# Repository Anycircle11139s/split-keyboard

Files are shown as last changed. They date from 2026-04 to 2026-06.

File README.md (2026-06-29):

# split-keyboard

Readme time...

I created a split keyboard, because I really enjoyed making the hackpad and I spend a lot of time on my computer and don't wanna get carpal tunnel. I spent a really long time making the split keyboard and it's a bit basic, but I like it. 

Screenshot 2026-04-14 at 10 44 15 am
This is the code, its pretty simple, but I didn't want to make it too complex as it is my first time working with zmk (I used kmk for the hackpad before)

Screenshot 2026-04-13 at 3 55 50 pm
This is my PCB, I spent a while placing the keys in a format that I liked, but I spet a lot longer routing the thing. I lowkenuinely spent like 7 hours just routing it :I

Screenshot 2026-04-13 at 3 56 20 pm
Screenshot 2026-04-13 at 3 56 32 pm

Here, I have the case, I'm pretty proud of it because there was no tutorial and I had to wing it, but it still turned out pretty well.Screenshot 2026-04-14 at 10 56 33 am

The schematic was pretty fun, I made hierarchial sheets and a rlly big keyboard matrix, it was overall pretty easy (the schematic)

BOM:

|Name |Purpose |Quantity|Total Cost (USD)|Link |Distributor |
|---|---|---|---|---|---|
|Soldering iron tip cleaner |To get solder off my soldering iron when soldering the split keyboard|1 |2.51 |https://www.aliexpress.com/item/1005011767599627.html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 |ali-express |
|Tweezers |So i can place small stuff on a board |1 |3.80 |https://www.aliexpress.com/item/1005008096741092.html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 |Ali-express |
|Wick |So if I make mistakes i can suck up the solder |1 |1.90 |https://www.aliexpress.com/item/1005005111965242.html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 |Ali-express |
|Helping hands |to allow me to solder all the stuff |1 |1.50 |https://www.aliexpress.com/item/1005011766151305.html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 |Ali-express |
|M3X4X5 Heat Insert Nut M3 Threaded|for inseting pcb t case |50 |2.88 |https://www.aliexpress.com/item/1005010775775055.html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 |Ali-express |
|Case printing and shipping |The case |1 |7.00 | |Printing Legion|
|PCB |The board which the components go on |1 |31.50 | |JLCPCB |
|xiao nRF52840 |microcontroller |2 |13.62 |https://www.aliexpress.com/item/1005006988954136.html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 |Ali-express |
|Diodes |to prevent ghosting |100 |0.86 |https://www.aliexpress.com/item/32947233235.html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|Ali-express |
|M2 screws |to hold it together |50 |1.90 |https://www.aliexpress.com/item/1005005070119421.html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 |Ali-express |
|Keycaps |to cover the keys |124 |3.93 |https://www.aliexpress.com/item/1005007360831985.html |Ali-express |
|Switches |Buttons for keyboard |110 |16.00 |https://www.aliexpress.com/item/1005004285423123.html |Ali-express |

<br>

<br>

Building keyboard:
<br>
So I spent a rlly long time sodlering everything together and after a couple bugs and troubleshooting, I finally got it working. I'm really proud of my design and I can't wait to show this off to all my friends and family!
<br>
<br>

WhatsApp Image 2026-06-30 at 09 35 08 (1)

https://github.com/user-attachments/assets/18d752bb-31d4-4ef4-a61a-be9153cc65bb

https://github.com/user-attachments/assets/6f350401-69de-47bb-a7fa-8a00cfc4a692

WhatsApp Image 2026-06-30 at 09 35 08

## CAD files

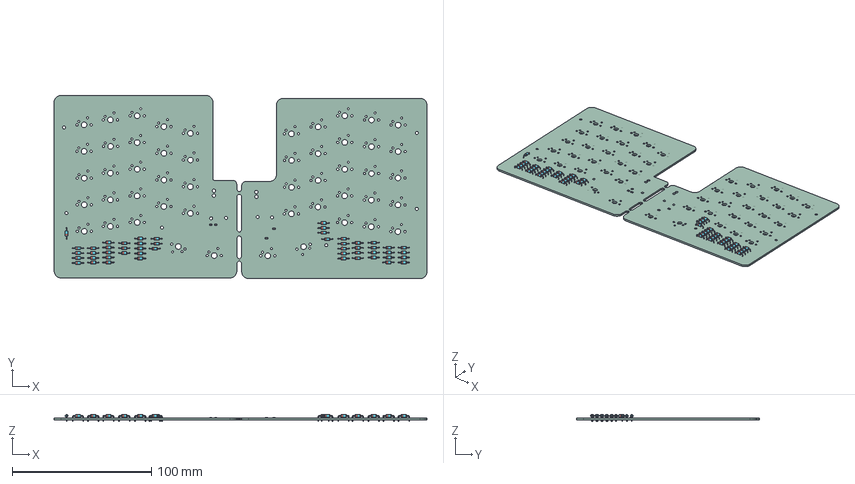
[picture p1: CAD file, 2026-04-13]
Split keyboard PCB/Split keyboard.step
267.4 x 131.4 x 5.01 mm
D_DO-35_SOD27_P7.62mm_Horizontal x 50
R_0805_2012Metric x 4
Split keyboard_PCB

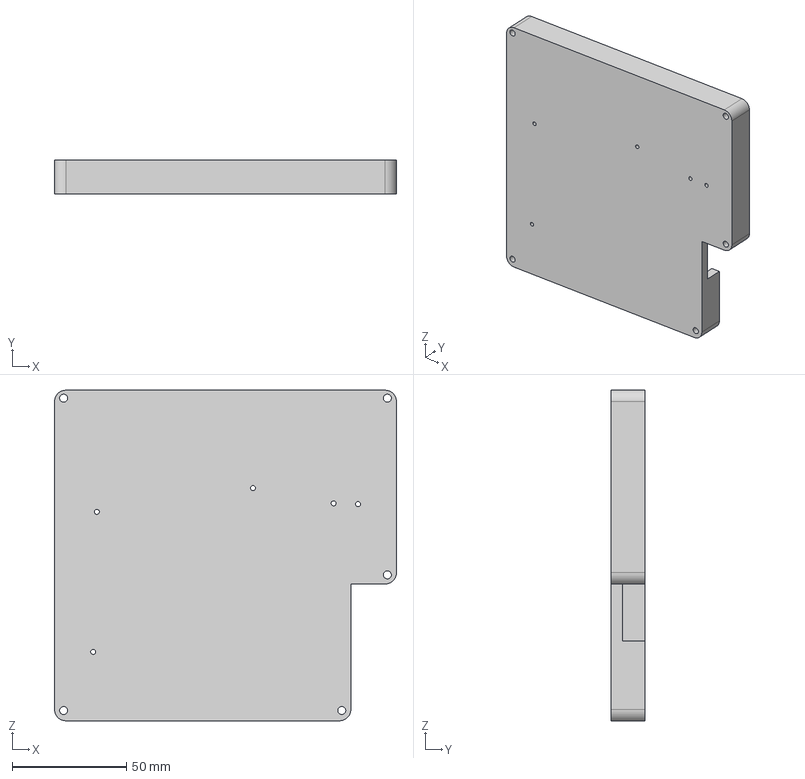
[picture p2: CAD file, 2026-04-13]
Splot keyboard Production/Left bottom split keyboard case.step
150.0 x 15.0 x 145.0 mm

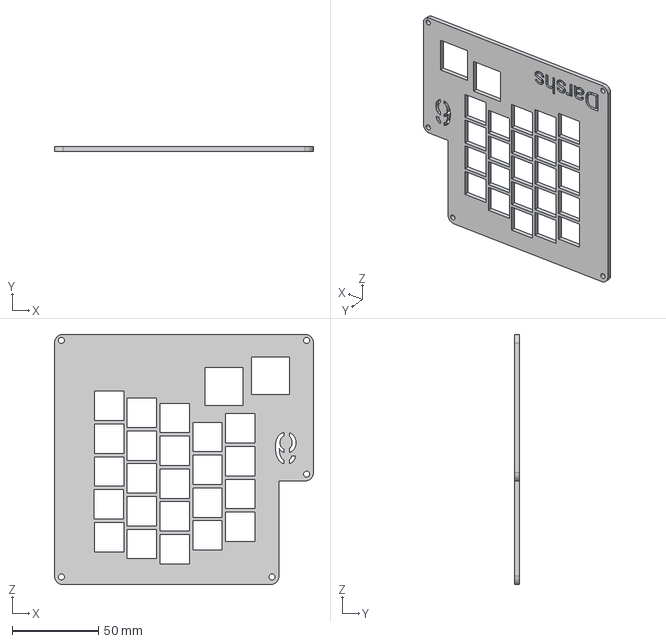
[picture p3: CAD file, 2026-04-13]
Splot keyboard Production/Left top split keyboard case.step
150.0 x 3.00 x 145.0 mm

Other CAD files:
Splot keyboard Production/Right bottom split keyboard case.step
Splot keyboard Production/Right top split keyboard case.step

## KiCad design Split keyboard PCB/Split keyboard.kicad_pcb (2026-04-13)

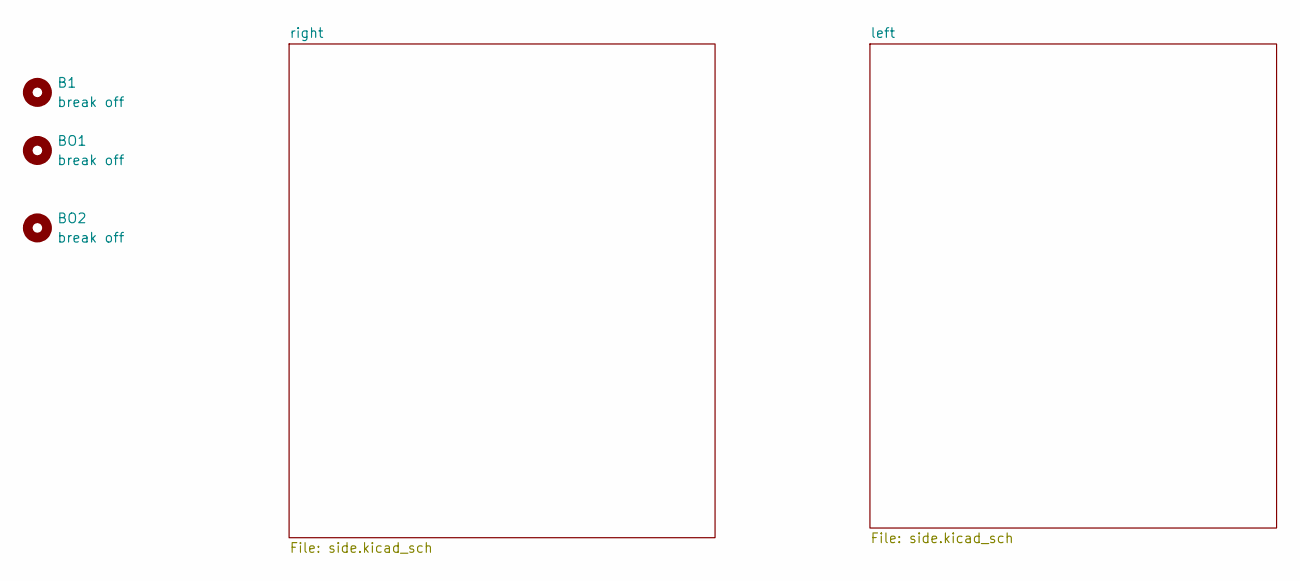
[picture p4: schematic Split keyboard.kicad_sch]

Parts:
B1: break off; mouse-bite-1mm-slot
BO1, BO2: break off; mouse-bite-1mm-slot

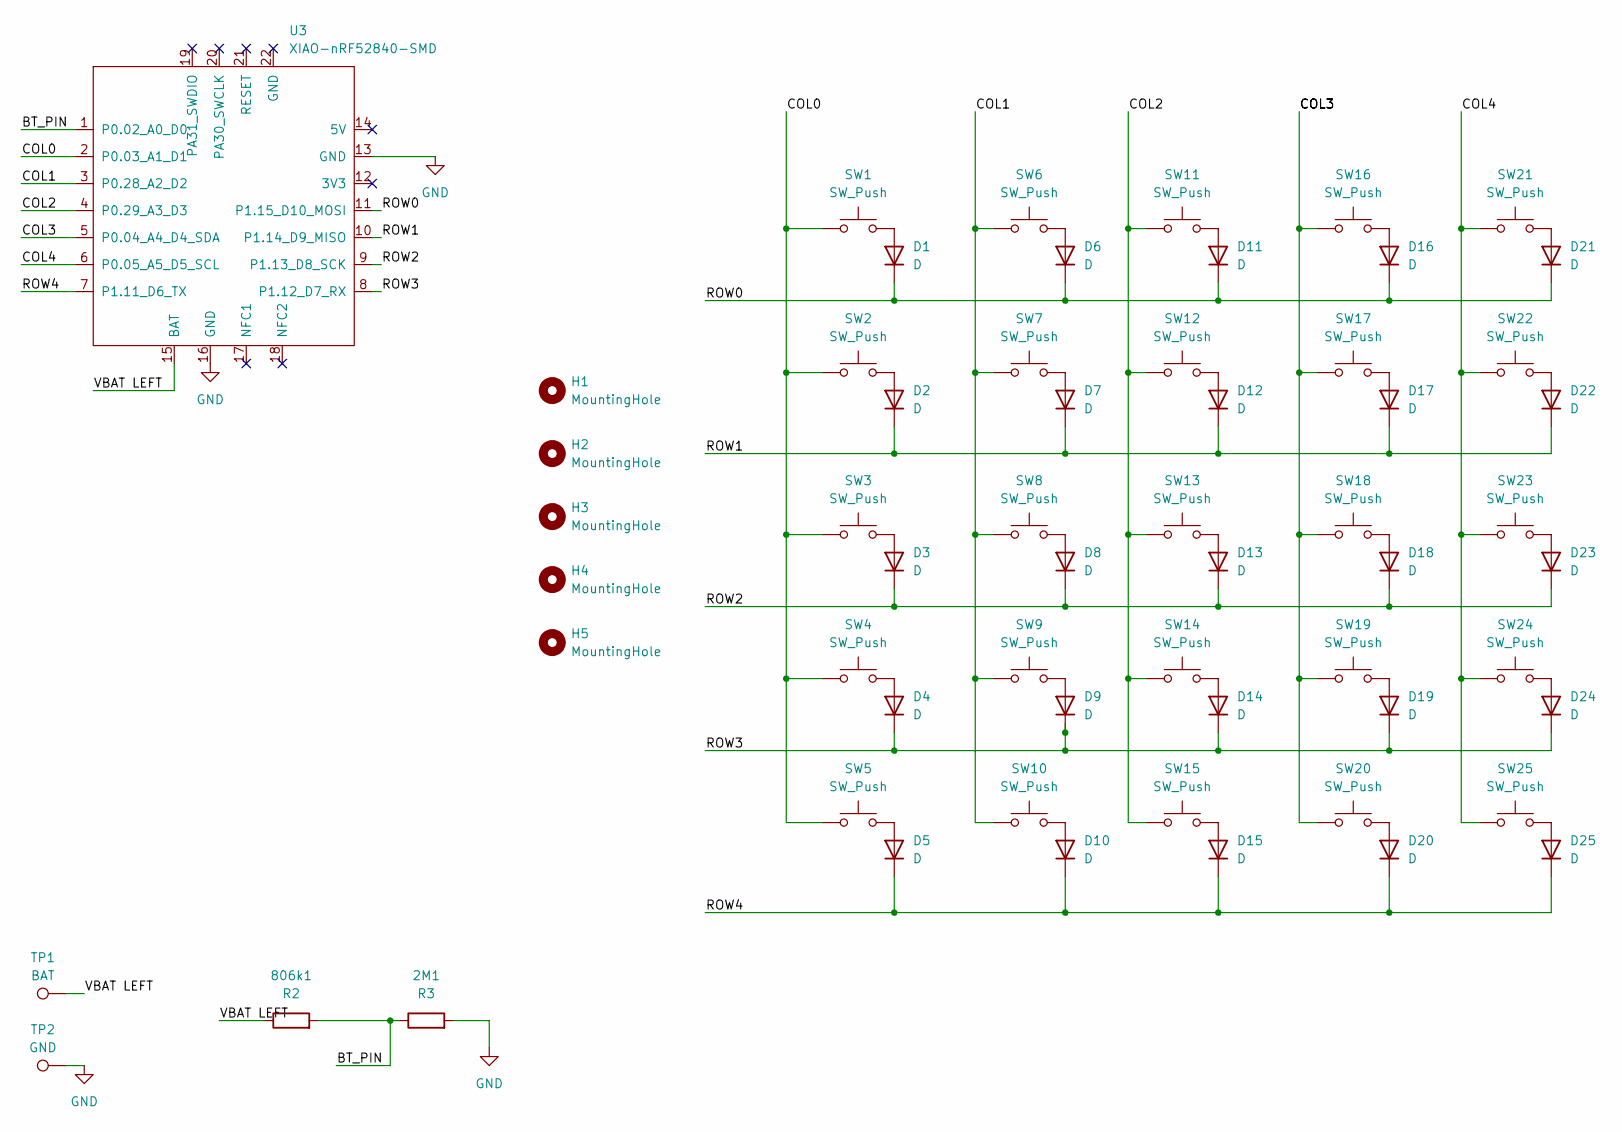
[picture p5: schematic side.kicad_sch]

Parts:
2M1: R3; R_0805_2012Metric
806k1: R2; R_0805_2012Metric
D1, D2, D3, D4, D5, D6, D7, D8, D9, D10, D11, D12, D13, D14, D15, D16, D17, D18, D19, D20, D21, D22, D23, D24, D25: D; D_DO-35_SOD27_P7.62mm_Horizontal
H1, H2, H3, H4, H5: MountingHole; MountingHole_2.2mm_M2_DIN965_Pad
SW1, SW2, SW3, SW4, SW5, SW6, SW7, SW8, SW9, SW10, SW11, SW12, SW13, SW14, SW15, SW16, SW17, SW18, SW19, SW20, SW21, SW22, SW23, SW24, SW25: SW_Push; SW_Cherry_MX_1.00u_PCB
TP1: BAT; TestPoint_Pad_D2.0mm
TP2: GND; TestPoint_Pad_D2.0mm
U3: XIAO-nRF52840-SMD; Modified XIAO nRF52840 SMD

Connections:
/left/BT_PIN: 2M1.1, 806k1.2, U3.1 (P0.02_A0_D0)
/left/COL0: SW1.1, SW2.1, SW3.1, SW4.1, SW5.1, U3.2 (P0.03_A1_D1)
/left/COL1: SW6.1, SW7.1, SW8.1, SW9.1, SW10.1, U3.3 (P0.28_A2_D2)
/left/COL2: SW11.1, SW12.1, SW13.1, SW14.1, SW15.1, U3.4 (P0.29_A3_D3)
/left/COL3: SW16.1, SW17.1, SW18.1, SW19.1, SW20.1, U3.5 (P0.04_A4_D4_SDA)
/left/COL4: SW21.1, SW22.1, SW23.1, SW24.1, SW25.1, U3.6 (P0.05_A5_D5_SCL)
/left/ROW0: D1.1 (K), D6.1 (K), D11.1 (K), D16.1 (K), D21.1 (K), U3.11 (P1.15_D10_MOSI)
/left/ROW1: D2.1 (K), D7.1 (K), D12.1 (K), D17.1 (K), D22.1 (K), U3.10 (P1.14_D9_MISO)
/left/ROW2: D3.1 (K), D8.1 (K), D13.1 (K), D18.1 (K), D23.1 (K), U3.9 (P1.13_D8_SCK)
/left/ROW3: D4.1 (K), D9.1 (K), D14.1 (K), D19.1 (K), D24.1 (K), U3.8 (P1.12_D7_RX)
/left/ROW4: D5.1 (K), D10.1 (K), D15.1 (K), D20.1 (K), D25.1 (K), U3.7 (P1.11_D6_TX)
/left/VBAT LEFT: 806k1.1, TP1.1, U3.15 (BAT)
GND: 2M1.2, TP2.1, U3.13 (GND), U3.16 (GND); also elsewhere on the board
unnamed: D1.2 (A), SW1.2
unnamed: D2.2 (A), SW2.2
unnamed: D3.2 (A), SW3.2
unnamed: D4.2 (A), SW4.2
unnamed: D5.2 (A), SW5.2
unnamed: D6.2 (A), SW6.2
unnamed: D7.2 (A), SW7.2
unnamed: D8.2 (A), SW8.2
unnamed: D9.2 (A), SW9.2
unnamed: D10.2 (A), SW10.2
unnamed: D11.2 (A), SW11.2
unnamed: D12.2 (A), SW12.2
unnamed: D13.2 (A), SW13.2
unnamed: D14.2 (A), SW14.2
unnamed: D15.2 (A), SW15.2
unnamed: D16.2 (A), SW16.2
unnamed: D17.2 (A), SW17.2
unnamed: D18.2 (A), SW18.2
unnamed: D19.2 (A), SW19.2
unnamed: D20.2 (A), SW20.2
unnamed: D21.2 (A), SW21.2
unnamed: D22.2 (A), SW22.2
unnamed: D23.2 (A), SW23.2
unnamed: D24.2 (A), SW24.2
unnamed: D25.2 (A), SW25.2

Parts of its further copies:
D26, D27, D28, D29, D30, D31, D32, D33, D34, D35, D36, D37, D38, D39, D40, D41, D42, D43, D44, D45, D46, D47, D48, D49, D50: D; D_DO-35_SOD27_P7.62mm_Horizontal
H6, H7, H8, H9, H10: MountingHole; MountingHole_2.2mm_M2_DIN965_Pad
R1: R2; R_0805_2012Metric
R2: R3; R_0805_2012Metric
SW26, SW27, SW28, SW29, SW30, SW31, SW32, SW33, SW34, SW35, SW36, SW37, SW38, SW39, SW40, SW41, SW42, SW43, SW44, SW45, SW46, SW47, SW48, SW49, SW50: SW_Push; SW_Cherry_MX_1.00u_PCB
TP3: BAT; TestPoint_Pad_D2.0mm
TP4: GND; TestPoint_Pad_D2.0mm
U4: XIAO-nRF52840-SMD; Modified XIAO nRF52840 SMD

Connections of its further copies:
/right/BT_PIN: R1.2, R2.1, U4.1 (P0.02_A0_D0)
/right/COL0: SW26.1, SW27.1, SW28.1, SW29.1, SW30.1, U4.2 (P0.03_A1_D1)
/right/COL1: SW31.1, SW32.1, SW33.1, SW34.1, SW35.1, U4.3 (P0.28_A2_D2)
/right/COL2: SW36.1, SW37.1, SW38.1, SW39.1, SW40.1, U4.4 (P0.29_A3_D3)
/right/COL3: SW41.1, SW42.1, SW43.1, SW44.1, SW45.1, U4.5 (P0.04_A4_D4_SDA)
/right/COL4: SW46.1, SW47.1, SW48.1, SW49.1, SW50.1, U4.6 (P0.05_A5_D5_SCL)
/right/ROW0: D26.1 (K), D31.1 (K), D36.1 (K), D41.1 (K), D46.1 (K), U4.11 (P1.15_D10_MOSI)
/right/ROW1: D27.1 (K), D32.1 (K), D37.1 (K), D42.1 (K), D47.1 (K), U4.10 (P1.14_D9_MISO)
/right/ROW2: D28.1 (K), D33.1 (K), D38.1 (K), D43.1 (K), D48.1 (K), U4.9 (P1.13_D8_SCK)
/right/ROW3: D29.1 (K), D34.1 (K), D39.1 (K), D44.1 (K), D49.1 (K), U4.8 (P1.12_D7_RX)
/right/ROW4: D30.1 (K), D35.1 (K), D40.1 (K), D45.1 (K), D50.1 (K), U4.7 (P1.11_D6_TX)
/right/VBAT LEFT: R1.1, TP3.1, U4.15 (BAT)
GND: R2.2, TP4.1, U4.13 (GND), U4.16 (GND); also elsewhere on the board
unnamed: D26.2 (A), SW26.2
unnamed: D27.2 (A), SW27.2
unnamed: D28.2 (A), SW28.2
unnamed: D29.2 (A), SW29.2
unnamed: D30.2 (A), SW30.2
unnamed: D31.2 (A), SW31.2
unnamed: D32.2 (A), SW32.2
unnamed: D33.2 (A), SW33.2
unnamed: D34.2 (A), SW34.2
unnamed: D35.2 (A), SW35.2
unnamed: D36.2 (A), SW36.2
unnamed: D37.2 (A), SW37.2
unnamed: D38.2 (A), SW38.2
unnamed: D39.2 (A), SW39.2
unnamed: D40.2 (A), SW40.2
unnamed: D41.2 (A), SW41.2
unnamed: D42.2 (A), SW42.2
unnamed: D43.2 (A), SW43.2
unnamed: D44.2 (A), SW44.2
unnamed: D45.2 (A), SW45.2
unnamed: D46.2 (A), SW46.2
unnamed: D47.2 (A), SW47.2
unnamed: D48.2 (A), SW48.2
unnamed: D49.2 (A), SW49.2
unnamed: D50.2 (A), SW50.2

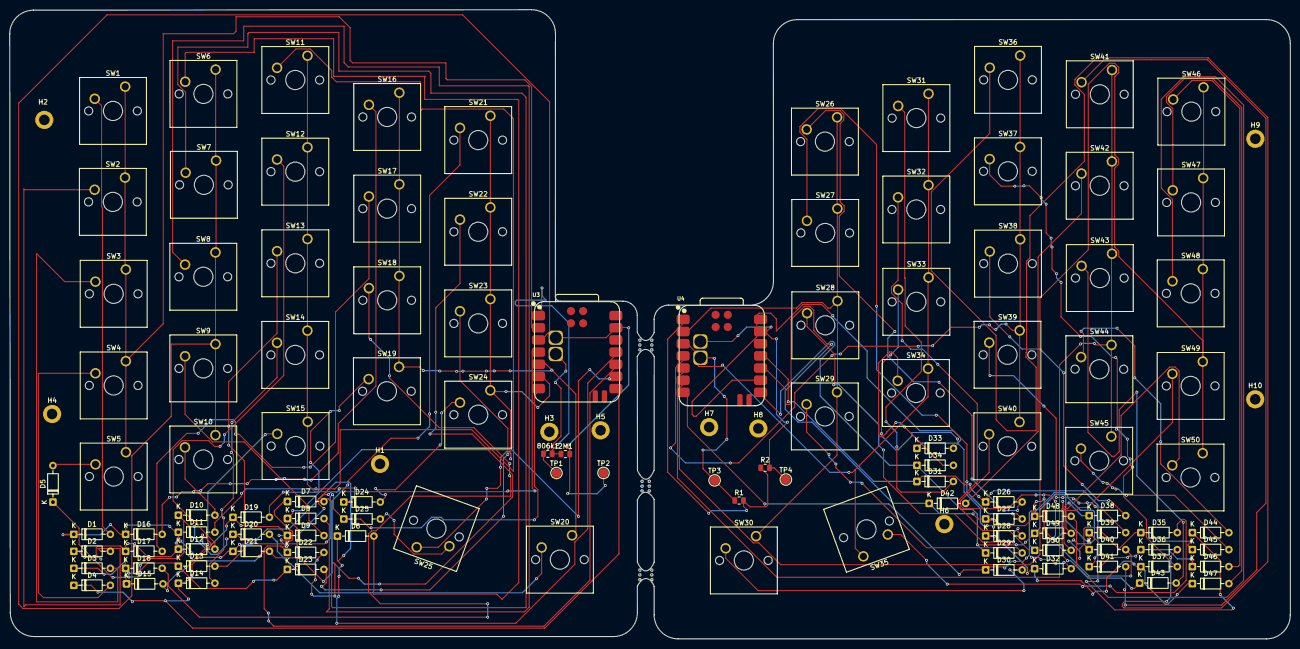
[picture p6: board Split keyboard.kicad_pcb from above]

Board: 2 copper layers, 267.4 x 131.4 mm, 123 parts (0 on the bottom side), 75 nets.
